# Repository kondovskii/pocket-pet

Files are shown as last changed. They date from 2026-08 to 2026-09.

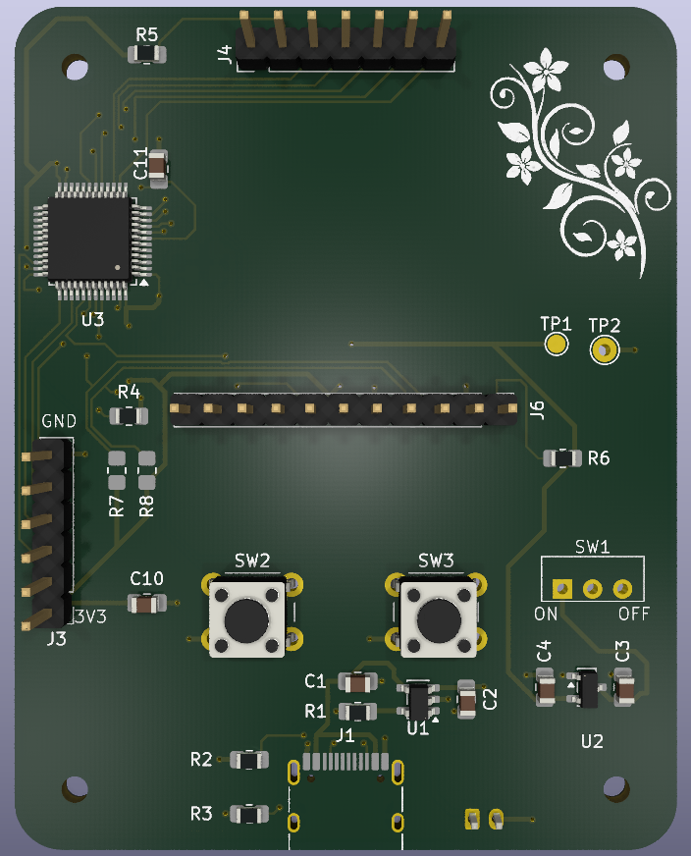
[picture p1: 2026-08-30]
docs/render-top.png

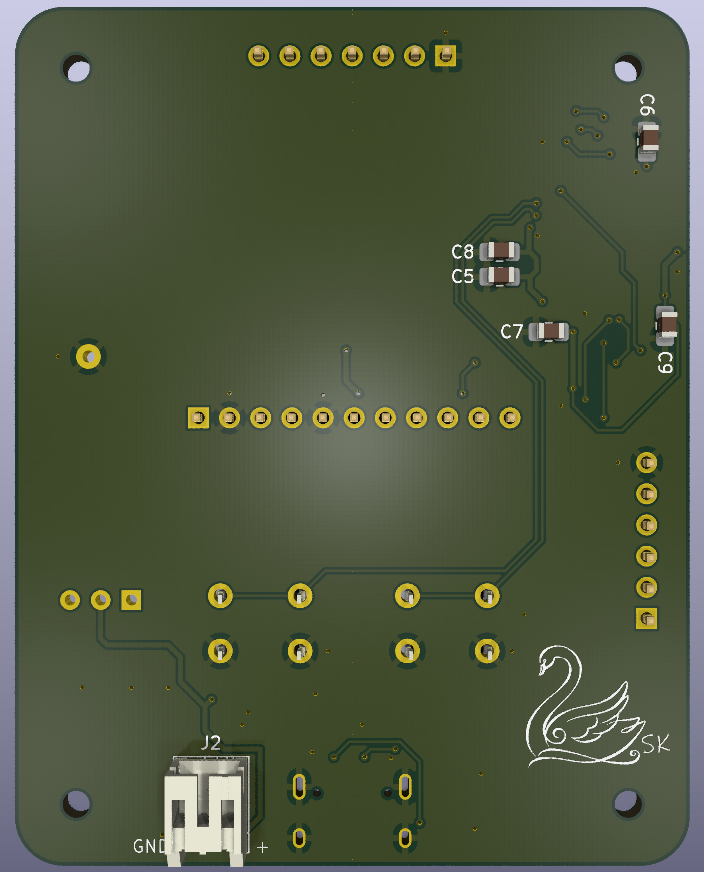
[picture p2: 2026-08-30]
docs/render-bottom.png

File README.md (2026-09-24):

# Pocket Pet

Battery-powered handheld virtual pet on a custom 2-layer PCB. STM32L433,
FreeRTOS, hand-written SSD1306 driver, wake-on-motion.

**Status:** working. Board assembled and running the full firmware — display,
accelerometer, buttons, and battery power all verified on the custom hardware.

## Why this project

Built to close four specific gaps: custom PCB design, bare-metal ARM
programming, RTOS usage, and datasheet-level driver work. Every part was chosen
and every driver written from the datasheet rather than pulled from a library,
so that each decision is defensible.

## Hardware

| Block | Part | Notes |
|---|---|---|
| MCU | STM32L433CCT6 (LQFP-48) | Cortex-M4F, 256K flash, low-power STOP2 modes |
| Charger | MCP73831 | ~196 mA charge current (R_PROG = 5.1 k) |
| Regulator | MCP1700-3302 | 3.3 V LDO, low quiescent current |
| Input | USB-C, charge only | 5.1 k CC1/CC2 pull-downs for correct sink advertisement |
| Display | SSD1306 128x64, SPI | Hand-written driver, no vendor library |
| Motion | LIS3DH, I2C | Hand-written driver; soldered direct, isolatable via R6 |
| Battery | 500 mAh LiPo | JST-PH |

2-layer FR4, designed in KiCad, fabricated by JLCPCB.

## Design decisions

**MSI at 32 MHz, not HSI16, not 80 MHz.** MSI is the oscillator the L4 wakes on
coming out of STOP mode, and it can be trimmed against an LSE crystal. 32 MHz
was chosen over the 80 MHz maximum because the workload — a 128x64 display
refresh and an accelerometer read — does not need it, and lower active current
is free. The power story for a battery device is duty cycle (STOP2 at roughly
1 uA versus milliamps awake), not clock rate.

**USB-C is charge-only.** No USB data. The 5.1 k pull-downs on CC1 and CC2 are
what make a charger treat the board as a valid sink; without them a compliant
USB-C supply provides no VBUS at all. Programming and debug go over SWD, which
keeps the firmware simpler and the BOM smaller.

**0 ohm jumpers on the peripheral rails.** R5 and R6 sit in series with the
display and accelerometer supplies so either can be cut to measure that
peripheral's current draw in isolation, or to remove it from the picture while
debugging.

**I2C pull-ups fitted but not populated.** R7 and R8 are marked DNP because the
LIS3DH module carries its own. Measured at 10 k, which is weak for 400 kHz on
a board with no ground plane, so the bus runs at 100 kHz — the workload is
roughly 60 bytes per second, so there is nothing to gain from the higher rate
and the slower edges have four times the rise-time margin.

**Peripherals soldered directly.** The original plan was female headers so
modules could be swapped. They were dropped because SW1, the power switch, is
surface-mounted flat to the board and cannot rise with them — sockets would
have left it recessed roughly 8.5 mm below the display plane and complicated
the enclosure. The 0 ohm rail jumpers (R5, R6) preserve the debugging benefit:
either peripheral can be isolated or current-measured by lifting one resistor.

**SWD broken out to a 6-pin header** with SWDIO, SWCLK, SWO, NRST, 3V3 and GND,
in ST-Link pin order.

## Display driver

Written from the SSD1306 datasheet rather than pulled from a library: SPI
transport with manual DC and CS control, the full initialisation sequence, a
1024-byte framebuffer, Bresenham line drawing, and a 5x7 column-major font.

**Draw to RAM, flush once.** Every primitive writes to the framebuffer and
nothing reaches the panel until `ssd1306_update_screen()`. Frames appear whole
rather than building up visibly, and the flush is a single 1024-byte SPI burst
instead of hundreds of small transfers.

**The font is column-major** because that matches the controller's own vertical
byte layout, so rendering a glyph is a single bit test per pixel with no
transposition.

**Clipping lives in one place.** Only `ssd1306_draw_pixel()` bounds-checks;
lines, rectangles and text all inherit it. One guard to get right instead of
six, and no way for them to disagree.

**Validated on a NUCLEO-L432KC with a 7-pin SPI module before the custom boards
arrived**, so that display bring-up and board bring-up could be debugged
independently. A blank screen on the custom board now means a hardware fault,
not an unproven driver.

## Motion driver

I2C driver for the LIS3DH, written from the datasheet: register map, burst
reads, and a WHO_AM_I identity check that fails loudly rather than returning
plausible garbage.

**Auto-increment must be requested explicitly.** Bit 7 of the register address
tells the part to advance its internal pointer across a burst. Without it,
reading six bytes from `OUT_X_L` returns the same register six times — all
three axes identical, which looks exactly like a dead sensor rather than a
protocol mistake.

**Block Data Update is enabled** so the part cannot refresh an output register
pair between the read of the low byte and the high byte. Without it, occasional
samples are the low half of one reading stitched to the high half of the next.

**Signed arithmetic shift for the 12-bit values.** Output is left-justified
16-bit; high-resolution mode makes only the top 12 bits meaningful. Shifting a
signed type sign-extends and preserves negative readings, where the same shift
on an unsigned type would turn -1 into 4095.

**The I2C address depends on the board, not the chip.** On the Nucleo bench
wiring SA0 and CS float, and the module's own strapping gives 0x19. On the
custom board J6 ties SA0 to ground and CS to 3V3, giving 0x18. The address
therefore lives in `pocket_pet_pins.h` behind a board selector rather than in
the driver, because it is a board fact.

## RTOS architecture

Three tasks, no shared state.

    inputTask    polls and debounces the buttons, detects shake, publishes events
    petTask      owns the pet state, applies events, ticks it forward once a second
    displayTask  redraws at 8 fps, taking a new state when one is available

Tasks communicate only through queues, and the pet state is passed **by value**
rather than by pointer — each task works on its own copy, so there is no shared
memory, no mutex, and no race to get wrong.

The two queues have deliberately different depths. The state queue is depth 1
because the display only ever cares about the newest state; a deeper one would
just mean rendering stale frames. The event queue is depth 4 because a dropped
button press is a bug, where a dropped frame is not.

**Input is edge-triggered, not level.** A press registers on the
released-to-pressed transition, so holding a button feeds the pet once rather
than continuously.

**The display task runs on a timer, not on the queue.** It was originally
blocked on `osWaitForever`, which meant it only redrew when the pet state
changed — once a second, far too slow for animation. It now wakes every 125 ms
and takes a new state if one is waiting, so rendering rate and simulation rate
are decoupled.

## Game design

Three stats decay on separate timescales: hunger fastest, then mood, then
energy. Any stat reaching zero starts a two-minute distress countdown with a
visible warning; ignoring it kills the pet. The countdown exists so that death
is a consequence of ignoring something, not a surprise.

**The lowest stat decides the pet's expression**, so it looks as bad as its
worst problem rather than averaging out and hiding the thing the player needs
to notice.

**Two buttons, four actions.** Left feeds. Right plays on a short press and
toggles sleep on a one-second hold. Shaking the board is a third input,
detected by comparing squared acceleration magnitude against a threshold —
squared, so the comparison needs no square root and no floating point.

**Sleep is the only way to recover energy**, and playing costs it, so the
stats interact rather than being three independent bars.

**Actions trigger a two-second reaction animation.** This confirms the press
registered, and gives the less-frequently-seen animations a reason to exist —
most moods map to slow-moving stats you rarely watch change.

## Known issues (v1.0)

Found during a design review after the boards were already at fab. Documented
rather than hidden — these are the v1.1 fix list.

- **No ground pour on either layer.** Every return path is a narrow trace, which
  raises loop inductance and leaves the MCP73831 with no thermal copper. Expect
  the charger to run warm and possibly fold back current.
- **No reverse-polarity protection on the battery input.** A backwards cell would
  destroy the charger. Mitigated only by silkscreen.
- **No load-sharing.** The load hangs off the battery node, so the board is not
  designed to run from USB with no cell installed.
- **No battery voltage sensing.** No way to report state of charge. A divider to
  an ADC pin is the fix.
- **Decoupling placement is loose** — several caps sit millimetres from the pins
  they serve, which without a plane makes them largely ineffective.
- **STAT pin unconnected**, so there is no charge indicator LED.
- Silkscreen needs a cleanup pass: unannotated mounting holes, overlapping value
  text, no pin-1 markers or header labels.
- **Cold joints on the USB-C VBUS pin killed the first assembly attempt.**
  VBUS and GND have multiple redundant pins; CC1 and CC2 have exactly one
  each, so a single bad joint silently kills power negotiation with no other
  symptom. Worth probing CC-to-GND for 5.1 k before troubleshooting anything
  else.
- **The Nucleo-32's ST-Link cannot program an external target.** Unlike
  Nucleo-64 and -144, it has no break-out SWD connector — the debugger is
  hardwired to the on-board MCU, and CN2 is reserved for reflashing the
  ST-Link's own processor. A standalone ST-Link V2 is required. Worth knowing
  before planning a bring-up around a Nucleo.
- Debug sessions corrupt I²C. With SWD active, lis3dh_init() fails intermittently; disconnecting the debugger makes it reliable.  SWDIO and SWCLK run adjacent to the I²C lines with no ground plane between them. Worth knowing that on this board a peripheral failure seen under the debugger may not be a real failure.
- **Task stacks were too small, and the first fix silently undid itself.**
  The display task ran on CubeMX's default 512 bytes, which `snprintf`, newlib
  reentrancy and the scaled bitmap blit comfortably exceed. The symptom was a
  HardFault minutes after boot, triggered by bursts of input, with nothing
  obviously stack-related in the trace. It was fixed once by hand, but the
  default task's stack size lives in generated code outside the USER CODE
  markers, so the next CubeMX regeneration quietly reverted it. Now set in the
  .ioc at 2 KB per task, with configCHECK_FOR_STACK_OVERFLOW enabled so any
  future overflow halts in a named hook rather than surfacing as an unrelated
  fault.
- **The battery arrived with its JST housing wired backwards.** With no
  reverse-polarity protection on v1.0 that would have destroyed the charger.
  Worth measuring cell polarity against the board's silkscreen before every
  first connection.
- **Cheap USB-C charger modules often omit the CC pull-downs.** A TP4056
  module appeared dead on a compliant USB-C supply because it never
  negotiated; it worked immediately from a legacy USB-A source. The same
  5.1 k resistors this board fits as R2/R3.
  - **Changing I2C speed in CubeMX did not update the generated timing register.**
  The .ioc read Standard Mode while `MX_I2C1_Init()` still carried the Fast
  Mode timing value, so the bus ran at 400 kHz regardless. With 10 k pull-ups
  and no ground plane that was marginal, and produced intermittent LIS3DH
  failures that looked like a driver or wiring fault. Toggling the mode and
  disabling custom timing both failed to force a recalculation; the value had
  to be entered by hand. Verify `hi2c1.Init.Timing` in i2c.c after any speed
  change rather than trusting the .ioc.

## Repository layout

    hardware/pocket-pet/     KiCad project, fab outputs under fab/
    firmware/pocket-pet-nucleo/   Bring-up project, NUCLEO-L432KC
    firmware/pocket-pet-board/    Custom board project
    docs/                    Schematic PDF, renders, BOM

## Building the firmware

Requires STM32CubeIDE. Import the project with "Copy projects into workspace"
unchecked so the IDE edits the repo in place; keep the workspace outside the
repository. The .ioc file is the source of truth for pin configuration — if you
change pins, regenerate from CubeMX rather than editing generated code.
Any value in generated code outside the USER CODE markers — task stack sizes,
heap size, peripheral settings — must be changed in the .ioc, not the source.
Hand edits there are overwritten on the next regeneration without warning.

## Sprites

Sprite data is not included in this repository. The bunny animations are from
[VegaJourney's 32x32 Bunny pack](https://toffeecraft.itch.io/bunny-pixel-animations) (licence permits use but
not redistribution), converted to 1-bit bitmaps.

To build: copy `firmware/common/pet_sprites.h.template` to `pet_sprites.h`
and supply your own sprite arrays. Any 1-bit bitmap works — 
`ssd1306_draw_bitmap()` takes row-major, MSB-first data, which is what
[image2cpp](https://javl.github.io/image2cpp/) produces with horizontal
orientation selected.

## License

MIT

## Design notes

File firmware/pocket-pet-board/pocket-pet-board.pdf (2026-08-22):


22/08/2026

pocket-pet-board Project
Configuration Report

## 1. Description

### 1.1. Project

Project Name | pocket-pet-board
Board Name | custom
Generated with: | STM32CubeMX 6.18.1
Date | 08/22/2026

### 1.2. MCU

MCU Series | STM32L4
MCU Line | STM32L4x3
MCU name | STM32L433CCTx
MCU Package | LQFP48
MCU Pin number | 48

### 1.3. Core(s) information

Core(s) | Arm Cortex-M4

## 2. Pinout Configuration

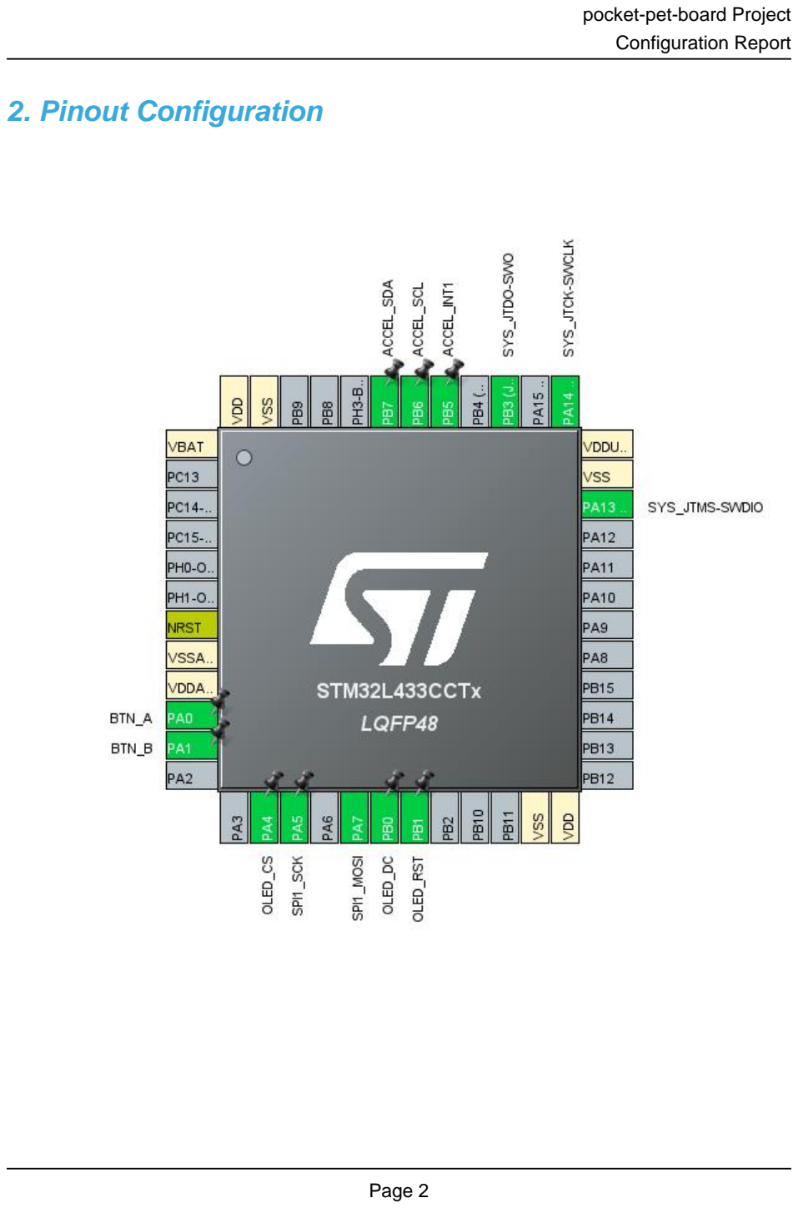
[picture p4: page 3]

## 3. Pins Configuration

Pin Number LQFP48 | Pin Name (function after reset) | Pin Type | Alternate Function(s) | Label
1 | VBAT | Power
7 | NRST | Reset
8 | VSSA/VREF- | Power
9 | VDDA/VREF+ | Power
10 | PA0 * | I/O | GPIO_Input | BTN_A
11 | PA1 * | I/O | GPIO_Input | BTN_B
14 | PA4 * | I/O | GPIO_Output | OLED_CS
15 | PA5 | I/O | SPI1_SCK
17 | PA7 | I/O | SPI1_MOSI
18 | PB0 * | I/O | GPIO_Output | OLED_DC
19 | PB1 * | I/O | GPIO_Output | OLED_RST
23 | VSS | Power
24 | VDD | Power
34 | PA13 (JTMS-SWDIO) | I/O | SYS_JTMS-SWDIO
35 | VSS | Power
36 | VDDUSB | Power
37 | PA14 (JTCK-SWCLK) | I/O | SYS_JTCK-SWCLK
39 | PB3 (JTDO-TRACESWO) | I/O | SYS_JTDO-SWO
41 | PB5 * | I/O | GPIO_Input | ACCEL_INT1
42 | PB6 | I/O | I2C1_SCL | ACCEL_SCL
43 | PB7 | I/O | I2C1_SDA | ACCEL_SDA
47 | VSS | Power
48 | VDD | Power

* The pin is affected with an I/O function

## 4. Clock Tree Configuration

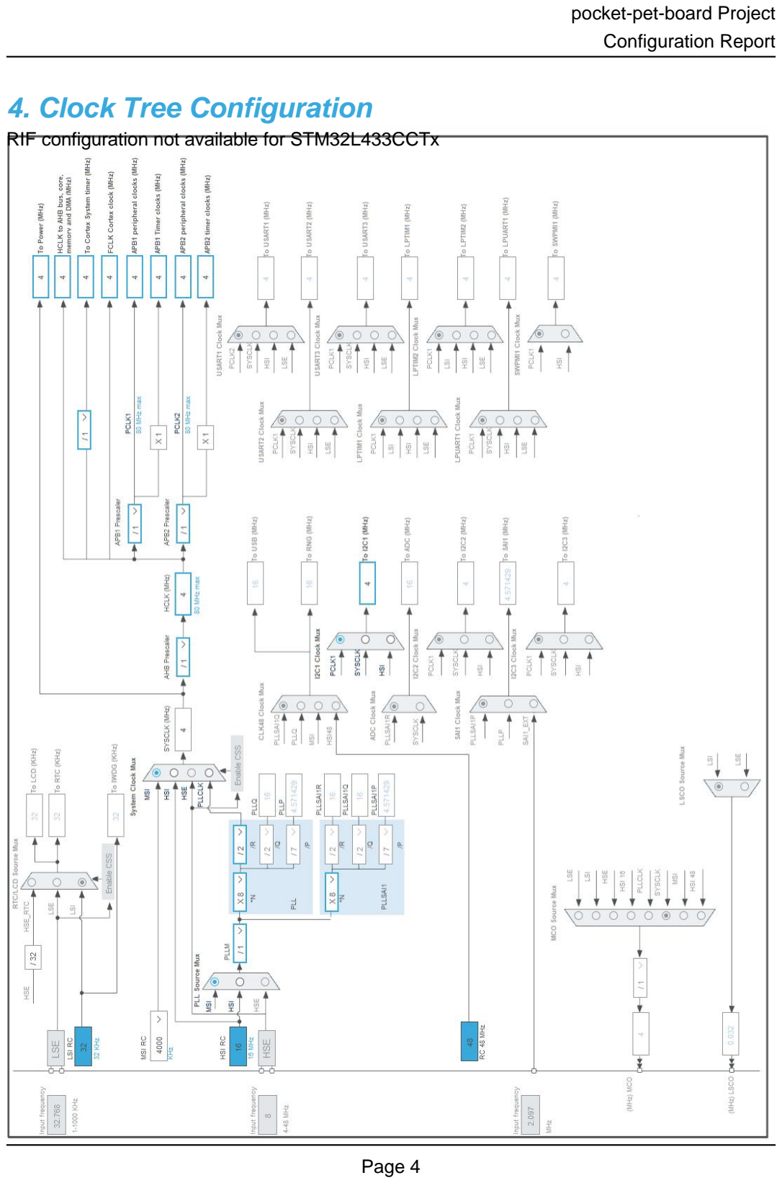
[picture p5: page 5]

RIF configuration not available for STM32L433CCTx

## 1. Power Consumption Calculator report

### 1.1. Microcontroller Selection

Series | STM32L4
Line | STM32L4x3
MCU | STM32L433CCTx
Datasheet | DS11449_Rev3

### 1.2. Parameter Selection

Temperature | 25
Vdd | 3.0

### 1.3. Battery Selection

Battery | Li-SOCL2(A3400)
Capacity | 3400.0 mAh
Self Discharge | 0.08 %/month
Nominal Voltage | 3.6 V
Max Cont Current | 100.0 mA
Max Pulse Current | 200.0 mA
Cells in series | 1
Cells in parallel | 1

### 1.4. Sequence

Step | Step1 | Step2
Mode | RUN | STOP2
Vdd | 3.0 | 3.0
Voltage Source | Battery | Battery
Range | Range1-High | NoRange
Fetch Type | SRAM2 | n/a
CPU Frequency | 80 MHz | 0 Hz
Clock Configuration | HSE BYP PLL | ALL CLOCKS OFF
Clock Source Frequency | 4 MHz | 0 Hz
Peripherals
Additional Cons. | 0 mA | 0 mA
Average Current | 8.71 mA | 1.06 µA
Duration | 0.1 ms | 0.9 ms
DMIPS | 100.0 | 0.0
Ta Max | 103.51 | 105
Category | In DS Table | In DS Table

### 1.5. Results

Sequence Time | 1 ms | Average Current | 871.95 µA
Battery Life | 5 months, 9 days, 16 hours | Average DMIPS | 100.0 DMIPS

### 1.6. Chart

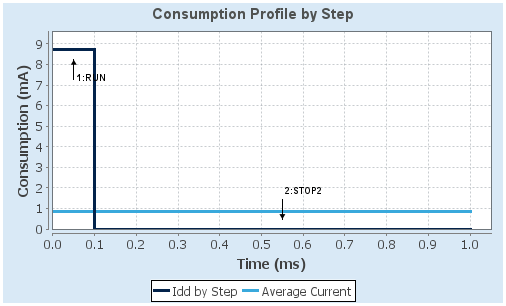
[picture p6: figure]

## 2. Software Project

### 2.1. Project Settings

Name | Value
Project Name | pocket-pet-board
Project Folder | C:\projects\pocket-pet\firmware\pocket-pet-board
Toolchain / IDE | EWARM V8.32
Firmware Package Name and Version | STM32Cube FW_L4 V1.18.2
Application Structure | Advanced
Generate Under Root | No
Do not generate the main() | No
Minimum Heap Size | 0x200
Minimum Stack Size | 0x400

### 2.2. Code Generation Settings

Name | Value
STM32Cube MCU packages and embedded software | Copy all used libraries into the project folder
Generate peripheral initialization as a pair of '.c/.h' files | No
Backup previously generated files when re-generating | No
Keep User Code when re-generating | Yes
Delete previously generated files when not re-generated | Yes
Set all free pins as analog (to optimize the power consumption) | No
Enable Full Assert | No

### 2.3. Advanced Settings - Generated Function Calls

Rank | Function Name | Peripheral Instance Name
1 | SystemClock_Config | RCC
2 | MX_GPIO_Init | GPIO
3 | MX_I2C1_Init | I2C1
4 | MX_SPI1_Init | SPI1

## 3. Peripherals and Middlewares Configuration

### 3.1. I2C1

I2C: I2C
3.1.1. Parameter Settings:

Timing configuration:

Custom Timing | Disabled
I2C Speed Mode | Standard Mode
I2C Speed Frequency (KHz) | 100
Rise Time (ns) | 100
Fall Time (ns) | 100
Coefficient of Digital Filter | 0
Analog Filter | Enabled
Timing | 0x00100D14 *
Slave Features:
Clock No Stretch Mode | Disabled
General Call Address Detection | Disabled
Primary Address Length selection | 7-bit
Dual Address Acknowledged | Disabled
Primary slave address | 0

### 3.2. RCC

3.2.1. Parameter Settings:

System Parameters:

VDD voltage (V) | 3.3
Instruction Cache | Enabled
Prefetch Buffer | Disabled
Data Cache | Enabled
Flash Latency(WS) | 0 WS (1 CPU cycle)
RCC Parameters:
HSI Calibration Value | 16
MSI Calibration Value | 0
MSI Auto Calibration | Disabled
HSE Startup Timout Value (ms) | 100
LSE Startup Timout Value (ms) | 5000
Power Parameters:
Power Regulator Voltage Scale | Power Regulator Voltage Scale 1

### 3.3. SPI1

Mode: Transmit Only Master
3.3.1. Parameter Settings:

Basic Parameters:

Frame Format | Motorola
Data Size | 8 Bits *
First Bit | MSB First
Clock Parameters:
Prescaler (for Baud Rate) | 2
Baud Rate | 2.0 MBits/s *
Clock Polarity (CPOL) | Low
Clock Phase (CPHA) | 1 Edge
Advanced Parameters:
CRC Calculation | Disabled
NSSP Mode | Enabled
NSS Signal Type | Software

### 3.4. SYS

Debug: Trace Asynchronous Sw Timebase Source: SysTick

* User modified value

## 4. System Configuration

### 4.1. GPIO configuration

IP | Pin | Signal | GPIO mode | GPIO pull/up pull down | Max Speed | User Label
I2C1 | PB6 | I2C1_SCL | Alternate Function Open Drain | No pull-up and no pull-down | Very High * | ACCEL_SCL
| PB7 | I2C1_SDA | Alternate Function Open Drain | No pull-up and no pull-down | Very High * | ACCEL_SDA
SPI1 | PA5 | SPI1_SCK | Alternate Function Push Pull | No pull-up and no pull-down | Very High *
| PA7 | SPI1_MOSI | Alternate Function Push Pull | No pull-up and no pull-down | Very High *
SYS | PA13 (JTMS-SWDIO) | SYS_JTMS-SWDIO | n/a | n/a | n/a
| PA14 (JTCK-SWCLK) | SYS_JTCK-SWCLK | n/a | n/a | n/a
| PB3 (JTDO-TRACESWO ) | SYS_JTDO-SWO | n/a | n/a | n/a
GPIO | PA0 | GPIO_Input | Input mode | Pull-up * | n/a | BTN_A
| PA1 | GPIO_Input | Input mode | Pull-up * | n/a | BTN_B
| PA4 | GPIO_Output | Output Push Pull | No pull-up and no pull-down | Low | OLED_CS
| PB0 | GPIO_Output | Output Push Pull | No pull-up and no pull-down | Low | OLED_DC
| PB1 | GPIO_Output | Output Push Pull | No pull-up and no pull-down | Low | OLED_RST
| PB5 | GPIO_Input | Input mode | No pull-up and no pull-down | n/a | ACCEL_INT1

### 4.2. DMA configuration

nothing configured in DMA service

### 4.3. NVIC configuration

4.3.1. NVIC
Interrupt Table | Enable | Preenmption Priority | SubPriority
Non maskable interrupt | true | 0 | 0
Hard fault interrupt | true | 0 | 0
Memory management fault | true | 0 | 0
Prefetch fault, memory access fault | true | 0 | 0
Undefined instruction or illegal state | true | 0 | 0
System service call via SWI instruction | true | 0 | 0
Debug monitor | true | 0 | 0
Pendable request for system service | true | 0 | 0
System tick timer | true | 15 | 0
PVD/PVM1/PVM2/PVM3/PVM4 interrupts through EXTI lines 16/35/36/37/38 | unused
Flash global interrupt | unused
RCC global interrupt | unused
I2C1 event interrupt | unused
I2C1 error interrupt | unused
SPI1 global interrupt | unused
FPU global interrupt | unused
4.3.2. NVIC Code generation
Enabled interrupt Table | Select for init sequence ordering | Generate IRQ handler | Call HAL handler
Non maskable interrupt | false | true | false
Hard fault interrupt | false | true | false
Memory management fault | false | true | false
Prefetch fault, memory access fault | false | true | false
Undefined instruction or illegal state | false | true | false
System service call via SWI instruction | false | true | false
Debug monitor | false | true | false
Pendable request for system service | false | true | false
System tick timer | false | true | true

* User modified value

## 5. System Views

5.1. Category view
5.1.1. Current

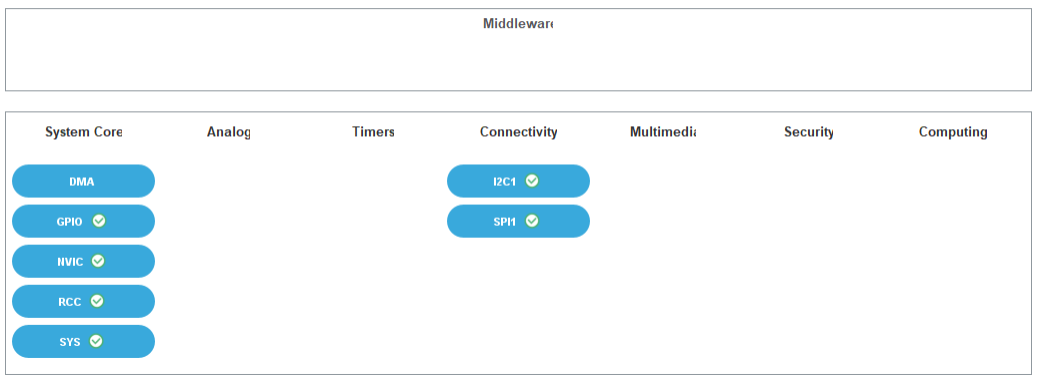
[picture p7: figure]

## 6. Docs & Resources

Type | Link
BSDL files | https://www.st.com/resource/en/bsdl_model/stm32l4_bsdl.zip
IBIS models | https://www.st.com/resource/en/ibis_model/stm32l4_ibis.zip
System View Description | https://www.st.com/resource/en/svd/stm32l4_svd.zip
Presentations | https://www.st.com/resource/en/product_presentation/stm32-stm8_embedded_software_solutions.pdf
Presentations | https://www.st.com/resource/en/product_presentation/stm32_eval-tools_portfolio.pdf
Presentations | https://www.st.com/resource/en/product_presentation/stm32_stm8_functi onal-safety-packages.pdf
Presentations | https://www.st.com/resource/en/product_presentation/stm32-stm8_software_development_tools.pdf
Presentations | https://www.st.com/resource/en/product_presentation/microcontrollers-stm32-family-overview.pdf
Presentations | https://www.st.com/resource/en/product_presentation/microcontrollers-stm32l4-series-product-overview.pdf
Brochures | https://www.st.com/resource/en/brochure/brstm32ulp.pdf
Flyers | https://www.st.com/resource/en/flyer/flstm32l4.pdf
Flyers | https://www.st.com/resource/en/flyer/flstm32nucleo.pdf
Flyers | https://www.st.com/resource/en/flyer/flstm32trust.pdf
Product Certifications | https://www.st.com/resource/en/certification_document/sesip-2000002-01-cert.pdf
Product Certifications | https://www.st.com/resource/en/certification_document/sesip-2000002-01-st2.pdf
Product Certifications | https://www.st.com/resource/en/certification_document/psa-certificate_stm32l4.pdf
Security Bulletin | https://www.st.com/resource/en/technical_note/tn1489-security-bulletin-tn1489stpsirt-physical-attacks-on-stm32-and-stm32cube-firmware-stmicroelectronics.pdf

Application Notes | https://www.st.com/resource/en/application_note/an1709-emc-design-guide-for-stm8-stm32-and-legacy-mcus-stmicroelectronics.pdf
Application Notes | https://www.st.com/resource/en/application_note/an4221-i2c-protocol-used-in-the-stm32-bootloader-stmicroelectronics.pdf
Application Notes | https://www.st.com/resource/en/application_note/an4555-getting-started-with-stm32l4-series-and-stm32l4-series-hardware-development-stmicroelectronics.pdf
Application Notes | https://www.st.com/resource/en/application_note/an4612-migrating-from-stm32l1-series-to-stm32l4-series-and-stm32l4-series-microcontrollers-stmicroelectronics.pdf
Application Notes | https://www.st.com/resource/en/application_note/an4616-migrating-from-stm32f401-and-stm32f411-lines-to-stm32l4-series-and-stm32l4-series-microcontrollers-stmicroelec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
Application Notes | https://www.st.com/resource/en/application_note/an4621-stm32l4-and-stm32l4-ultralowpower-features-overview-stmicroelectronics.pdf
Application Notes | https://www.st.com/resource/en/application_note/an4629-adc-hardware-oversampling-for-microcontrollers-of-the-stm32-l0-and-l4-series-stmicroelectronics.pdf
Application Notes | https://www.st.com/resource/en/application_note/an4649-migrating-from-stm32f1-series-to-stm32l4-series--stm32l4-series-microntrollers-stmicroelectronics.pdf
Application Notes | https://www.st.com/resource/en/application_note/an4655-virtually-increasing-the-number-of-serial-communication-peripherals-in-stm32-applications-stmicroelectronics.p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
Application Notes | https://www.st.com/resource/en/application_note/an4726-stm32cube-firmware-examples-for-stm32l4-series-and-stm32l4-series-stmicroelectronics.pdf
Application Notes | https://www.st.com/resource/en/application_note/an4729-stm32l0l4-firewall-overview-stmicroelectronics.pdf
Application Notes | https://www.st.com/resource/en/application_note/an4730-using-the-firewall-embedded-in-stm32l0l4l4-series-mcus-for-secure-access-to-sensitive-parts-of-code-and-data-s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
Application Notes | https://www.st.com/resource/en/application_note/an4750-handling-of-soft-errors-in-stm32-applications-stmicroelectronics.pdf

Application Notes | https://www.st.com/resource/en/application_note/an4754-migrating-between-stm32l486xx476xx-and-stm32l443xx433xx-microcontrollers-stmicroelectronics.pdf
Application Notes | https://www.st.com/resource/en/application_note/an4803-highspeed-si-simulations-using-ibis-and-boardlevel-simulations-using-hyperlynx-si-on-stm32-mcus-and-mpus-stmic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
Application Notes | https://www.st.com/resource/en/application_note/an4809-migrating-between-stm32l0-series-and-stm32l4-series--stm32l4-series-microcontrollers-stmicroelectronics.pdf
Application Notes | https://www.st.com/resource/en/application_note/an4821-migrating-from-stm32f405415-line-and-stm32f407417-line-to-stm32l4-series-and-stm32l4-series-microcontrollers-s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
Application Notes | https://www.st.com/resource/en/application_note/an4831-migrating-from-stm32f2x5-line-to-stm32l4-series-and-stm32l4-series-microcontrollers-stmicroelectronics.pdf
Application Notes | https://www.st.com/resource/en/application_note/an4832-migrating-from-stm32f303-line-to-stm32l4-series-and-stm32l4-series-microcontrollers-stmicroelectronics.pdf
Application Notes | https://www.st.com/resource/en/application_note/an4990-getting-started-with-sigmadelta-digital-interface-on-applicable-stm32-microcontrollers-stmicroelectronics.pdf
Application Notes | https://www.st.com/resource/en/application_note/an4995-using-an-electromyogram-technique-to-detect-muscle-activity-stmicroelectronics.pdf
Application Notes | https://www.st.com/resource/en/application_note/an5012-analogtodigital-audio-conversion-example-using-stm32l4-series-microcontroller-peripherals-stmicroelectronics.p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
Application Notes | https://www.st.com/resource/en/application_note/an5027-interfacing-pdm-digital-microphones-using-stm32-mcus-and-mpus-stmicroelectronics.pdf
Application Notes | https://www.st.com/resource/en/application_note/an4899-stm32-microcontroller-gpio-hardware-settings-and-lowpower-consumption-stmicroelectronics.pdf
Application Notes | https://www.st.com/resource/en/application_note/an5612-esd-protection-of-stm32-mcus-and-mpus-stmicroelectronics.pdf

Application Notes | https://www.st.com/resource/en/application_note/an4991-how-to-wake-up-an-stm32-microcontroller-from-lowpower-mode-with-the-usart-or-the-lpuart-stmicroelectronics.pdf
Application Notes | https://www.st.com/resource/en/application_note/an4838-introduction-to-memory-protection-unit-management-on-stm32-mcus-stmicroelectronics.pdf
Application Notes | https://www.st.com/resource/en/application_note/an4879-introduction-to-usb-hardware-and-pcb-guidelines-using-stm32-mcus-stmicroelectronics.pdf
Application Notes | https://www.st.com/resource/en/application_note/an5372-migrating-from-stm32l4-and-stm32l4--to-stm32u5-mcus-stmicroelectronics.pdf
Application Notes | https://www.st.com/resource/en/application_note/an5225-introduction-to-usb-typec-power-delivery-for-stm32-mcus-and-mpus-stmicroelectronics.pdf
Application Notes | https://www.st.com/resource/en/application_note/an4777-how-to-optimize-power-consumption-on-stm32-mcus-stmicroelectronics.pdf
Application Notes | https://www.st.com/resource/en/application_note/an4894-how-to-use-eeprom-emulation-on-stm32-mcus-stmicroelectronics.pdf
Application Notes | https://www.st.com/resource/en/application_note/an5537-how-to-use-adc-oversampling-techniques-to-improve-signaltonoise-ratio-on-stm32-mcus-stmicroelectronics.pdf
Application Notes | https://www.st.com/resource/en/application_note/an5690-how-to-use-vrefbuf-peripheral-on-stm32-mcus-and-mpus-stmicroelectronics.pdf
Application Notes | https://www.st.com/resource/en/application_note/an4230-introduction-to-random-number-generation-validation-using-the-nist-statistical-test-suite-for-stm32-mcus-and-m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
Application Notes | https://www.st.com/resource/en/application_note/an2548-introduction-to-dma-controller-for-stm32-mcus-stmicroelectronics.pdf
Application Notes | https://www.st.com/resource/en/application_note/an2867-guidelines-for-oscillator-design-on-stm8afals-and-stm32-mcusmpus-stmicroelectronics.pdf
Application Notes | https://www.st.com/resource/en/application_note/an3236-how-to-increase-the-number-of-touchkeys-for-touch-sensing-applications-on-stm32-mcus-stmicroelectronics.pdf

Application Notes | https://www.st.com/resource/en/application_note/an3960-guidelines-for-esd-for-touch-sensing-applications-on-stm32-mcus-stmicroelectronics.pdf
Application Notes | https://www.st.com/resource/en/application_note/an4013-introduction-to-timers-for-stm32-mcus-stmicroelectronics.pdf
Application Notes | https://www.st.com/resource/en/application_note/an4277-how-to-use-pwm-shutdown-for-motor-control-and-digital-power-conversion-on-stm32-mcus-stmicroelectronics.pdf
Application Notes | https://www.st.com/resource/en/application_note/an4299-how-to-improve-conducted-noise-robustness-for-touch-sensing-applications-on-stm32-mcus-stmicroelectronics.pdf
Application Notes | https://www.st.com/resource/en/application_note/an4310-how-to-choose-the-sampling-capacitor-for-touch-sensing-applications-on-stm32-mcus-stmicroelectronics.pdf
Application Notes | https://www.st.com/resource/en/application_note/an4312-how-to-design-surface-sensors-for-touch-sensing-applications-on-stm32-mcus-stmicroelectronics.pdf
Application Notes | https://www.st.com/resource/en/application_note/an4316-how-to-tune-touch-sensing-applications-on-stm32-mcus-stmicroelectronics.pdf
Application Notes | https://www.st.com/resource/en/application_note/an4635-how-to-optimize-lpuart-power-consumption-on-stm32-mcus-stmicroelectronics.pdf
Application Notes | https://www.st.com/resource/en/application_note/an4908-getting-started-with-usart-automatic-baud-rater-detection-for-stm32-mcus-stmicroelectronics.pdf
Application Notes | https://www.st.com/resource/en/application_note/an5156-introduction-to-security-for-stm32-mcus-stmicroelectronics.pdf
Application Notes | https://www.st.com/resource/en/application_note/an5543-guidelines-for-enhanced-spi-communication-on-stm32-mcus-and-mpus-stmicroelectronics.pdf
Application Notes | https://www.st.com/resource/en/application_note/cd00211314-how-to-optimize-the-adc-accuracy-in-the-stm32-mcus-stmicroelectronics.pdf
Application Notes | https://www.st.com/resource/en/application_note/an2639-soldering-recommendations-and-package-information-for-leadfree-ecopack2-mcus-and-mpus-stmicroelectronics.pdf

Application Notes | https://www.st.com/resource/en/application_note/an3154-how-to-use-can-protocol-in-bootloader-on-stm32-mcus-stmicroelectronics.pdf
Application Notes | https://www.st.com/resource/en/application_note/an6099-migrating-from-stm32l4-to-stm32u0-mcus-stmicroelectronics.pdf
Application Notes | https://www.st.com/resource/en/application_note/an4566-how-to-extend-the-dac-performance-on-stm32-mcus-stmicroelectronics.pdf
Application Notes | https://www.st.com/resource/en/application_note/an5105-getting-started-with-touch-sensing-control-on-stm32-mcus-stmicroelectronics.pdf
Application Notes | https://www.st.com/resource/en/application_note/an6051-migrating-from-stm32l4-and-stm32l4-to-stm32u3-mcus-stmicroelectronics.pdf
Application Notes | https://www.st.com/resource/en/application_note/an5647-the-goertzel-algorithm-to-compute-individual-terms-of-the-discrete-fourier-transform-dft-in-stm32-products-stm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
Application Notes | https://www.st.com/resource/en/application_note/an2606-introduction-to-system-memory-boot-mode-on-stm32-mcus-stmicroelectronics.pdf
Application Notes | https://www.st.com/resource/en/application_note/an5036-guidelines-for-thermal-management-on-stm32-mcus-and-mpus-stmicroelectronics.pdf
Application Notes | https://www.st.com/resource/en/application_note/an3126-how-to-use-dac-for-audio-and-waveform-generation-on-stm32-mcus-and-mpus-stmicroelectronics.pdf
Application Notes | https://www.st.com/resource/en/application_note/an3155-how-to-use-usart-protocol-in-bootloader-on-stm32-mcus-stmicroelectronics.pdf
Application Notes | https://www.st.com/resource/en/application_note/an3156-how-to-use-usb-dfu-protocol-in-bootloader-on-stm32-mcus-stmicroelectronics.pdf
Application Notes | https://www.st.com/resource/en/application_note/an4286-how-to-use-spi-protocol-in-bootloader-on-stm32-mcus-stmicroelectronics.pdf
Application Notes | https://www.st.com/resource/en/application_note/an4746-how-to-optimize-power-and-performance-on-stm32l4-and-stm32l4-mcus-stmicroelectronics.pdf
Application Notes | https://www.st.com/resource/en/application_note/an4759-introduction-to-using-the-hardware-realtime-clock-rtc-and-the-tamper-management-unit-tamp-for-stm32-mcus-stmic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
Application Notes | https://www.st.com/resource/en/application_note/an4760-introduction-to-

| quadspi-interface-for-stm32-mcus-and-mpus-stmicroelectronics.pdf
Application Notes | https://www.st.com/resource/en/application_note/an4776-how-to-use-generalpurpose-timer-peripheral-on-stm32-mcus-stmicroelectronics.pdf
Application Notes | https://www.st.com/resource/en/application_note/an4989-introduction-to-debug-toolbox-for-stm32-mcus-stmicroelectronics.pdf
Application Notes | https://www.st.com/resource/en/application_note/an5138-migrating-from-stm32l4-and-stm32l4-to-stm32l5-mcus-stmicroelectronics.pdf
Application Notes | https://www.st.com/resource/en/application_note/an5408-migrating-from-stm32l0-stm32l1-and-stm32l4-associated-with-sx12xx-transceivers-to-stm32wl5xex-mcus-stmicroelec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
Errata Sheets | https://www.st.com/resource/en/errata_sheet/es0318-stm32l431xx432xx433xx442xx443xx-device-errata-stmicroelectronics.pdf
Datasheet | https://www.st.com/resource/en/datasheet/dm00257192.pdf
Programming Manuals | https://www.st.com/resource/en/programming_manual/pm0214-stm32-cortexm4-mcus-and-mpus-programming-manual-stmicroelectronics.pdf
Reference Manuals | https://www.st.com/resource/en/reference_manual/rm0394-stm32l41xxx42xxx43xxx44xxx45xxx46xxx-advanced-armbased-32bit-mcus-stmicroelectronics.pdf
Technical Notes & Articles | https://www.st.com/resource/en/technical_note/tn1163-description-of-wlcsp-for-microcontrollers-and-recommendations-for-its-use-stmicroelectronics.pdf
Technical Notes & Articles | https://www.st.com/resource/en/technical_note/tn1205-tape-and-reel-shipping-media-for-stm8-and-stm32-microcontrollers-in-fpn-packages-stmicroelectronics.pdf
Technical Notes & Articles | https://www.st.com/resource/en/technical_note/tn1206-tape-and-reel-shipping-media-for-stm8-and-stm32-microcontrollers-in-qfp-packages-stmicroelectronics.pdf
Technical Notes & Articles | https://www.st.com/resource/en/technical_note/tn1207-tape-and-reel-shipping-media-for-stm8-and-stm32-microcontrollers-in-so-packages-stmicroelectronics.pdf
Technical Notes & Articles | https://www.st.com/resource/en/technical_note/tn1208-tape-and-reel-shipping-media-for-stm8-and-stm32-microcontrollers-in-tssop-and-ssop-packages-stmicroelectronics.p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

Technical Notes & Articles | https://www.st.com/resource/en/technical_note/tn1433-reference-device-marking-schematics-for-stm32-microcontrollers-and-microprocessors-stmicroelectronics.pdf
Technical Notes & Articles | https://www.st.com/resource/en/technical_note/tn1204-tape-and-reel-shipping-media-for-stm32-devices-in-bga-packages-stmicroelectronics.pdf
User Manuals | https://www.st.com/resource/en/user_manual/um2305-stm32l4-and-stm32l4-series-safety-manual-stmicroelectronics.pdf
User Manuals | https://www.st.com/resource/en/user_manual/um3166-stm32l4-and-stm32l4-series-ulcsaiec-607301603351-selftest-library-user-guide-stmicroelectronics.pdf

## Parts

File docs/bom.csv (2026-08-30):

Reference | Qty | Value | LCSC | DNP | Exclude from BOM | Exclude from Board | Exclude from Simulation | Exclude from Position Files | Footprint | Datasheet
C1,C2,C10 | 3 | 4.7uF | C1779 |  |  |  |  | ${EXCLUDE_FROM_POS_FILES} | Capacitor_SMD:C_0805_2012Metric_Pad1.18x1.45mm_HandSolder
C3 | 1 | 1uF | C28323 |  |  |  |  | ${EXCLUDE_FROM_POS_FILES} | Capacitor_SMD:C_0805_2012Metric_Pad1.18x1.45mm_HandSolder
C4 | 1 | 2.2uF | C377773 |  |  |  |  | ${EXCLUDE_FROM_POS_FILES} | Capacitor_SMD:C_0805_2012Metric_Pad1.18x1.45mm_HandSolder
C5,C6,C7,C8,C9,C11 | 6 | 100nF | C49678 |  |  |  |  | ${EXCLUDE_FROM_POS_FILES} | Capacitor_SMD:C_0805_2012Metric_Pad1.18x1.45mm_HandSolder
J1 | 1 | USB_C_Receptacle_USB2.0_16P | C165948 |  |  |  |  | ${EXCLUDE_FROM_POS_FILES} | Connector_USB:USB_C_Receptacle_HRO_TYPE-C-31-M-12 | https://www.usb.org/sites/default/files/documents/usb_type-c.zip
J2 | 1 | Conn_01x02 | C157932 |  |  |  |  | ${EXCLUDE_FROM_POS_FILES} | Connector_JST:JST_PH_S2B-PH-K_1x02_P2.00mm_Horizontal
J3 | 1 | Conn_01x06 |  |  |  |  |  | ${EXCLUDE_FROM_POS_FILES} | Connector_PinHeader_2.54mm:PinHeader_1x06_P2.54mm_Vertical
J4 | 1 | Conn_01x07 |  |  |  |  |  | ${EXCLUDE_FROM_POS_FILES} | Connector_PinHeader_2.54mm:PinHeader_1x07_P2.54mm_Vertical
J6 | 1 | Conn_01x11 |  |  |  |  |  | ${EXCLUDE_FROM_POS_FILES} | Connector_PinHeader_2.54mm:PinHeader_1x11_P2.54mm_Vertical
R1,R2,R3 | 3 | 5.1k | C27834 |  |  |  |  | ${EXCLUDE_FROM_POS_FILES} | Resistor_SMD:R_0805_2012Metric_Pad1.20x1.40mm_HandSolder
R4 | 1 | 10k | C2907219 |  |  |  |  | ${EXCLUDE_FROM_POS_FILES} | Resistor_SMD:R_0805_2012Metric_Pad1.20x1.40mm_HandSolder
R5,R6 | 2 | 0R | C17477 |  |  |  |  | ${EXCLUDE_FROM_POS_FILES} | Resistor_SMD:R_0805_2012Metric_Pad1.20x1.40mm_HandSolder
R7,R8 | 2 | 4.7k | C2907264 | DNP |  |  |  | ${EXCLUDE_FROM_POS_FILES} | Resistor_SMD:R_0805_2012Metric_Pad1.20x1.40mm_HandSolder
SW1 | 1 | SW_SPDT |  |  |  |  |  | ${EXCLUDE_FROM_POS_FILES} | pocket-pet:SW_Slide_SS12D00G3_P2.5mm
SW2,SW3 | 2 | SW_Push |  |  |  |  |  | ${EXCLUDE_FROM_POS_FILES} | Button_Switch_THT:SW_PUSH_6mm
TP1 | 1 | TestPoint |  |  |  |  |  | ${EXCLUDE_FROM_POS_FILES} | TestPoint:TestPoint_Pad_D1.5mm
TP2 | 1 | TestPoint |  |  |  |  |  | ${EXCLUDE_FROM_POS_FILES} | TestPoint:TestPoint_THTPad_D2.0mm_Drill1.0mm
U1 | 1 | MCP73831-2-OT | C424093 |  |  |  |  | ${EXCLUDE_FROM_POS_FILES} | Package_TO_SOT_SMD:SOT-23-5 | http://ww1.microchip.com/downloads/en/DeviceDoc/20001984g.pdf
U2 | 1 | MCP1700x-330xxTT | C39051 |  |  |  |  | ${EXCLUDE_FROM_POS_FILES} | Package_TO_SOT_SMD:SOT-23 | http://ww1.microchip.com/downloads/en/DeviceDoc/20001826D.pdf
U3 | 1 | STM32L433CCTx | C110061 |  |  |  |  | ${EXCLUDE_FROM_POS_FILES} | Package_QFP:LQFP-48_7x7mm_P0.5mm | https://www.st.com/resource/en/datasheet/stm32l433cc.pdf

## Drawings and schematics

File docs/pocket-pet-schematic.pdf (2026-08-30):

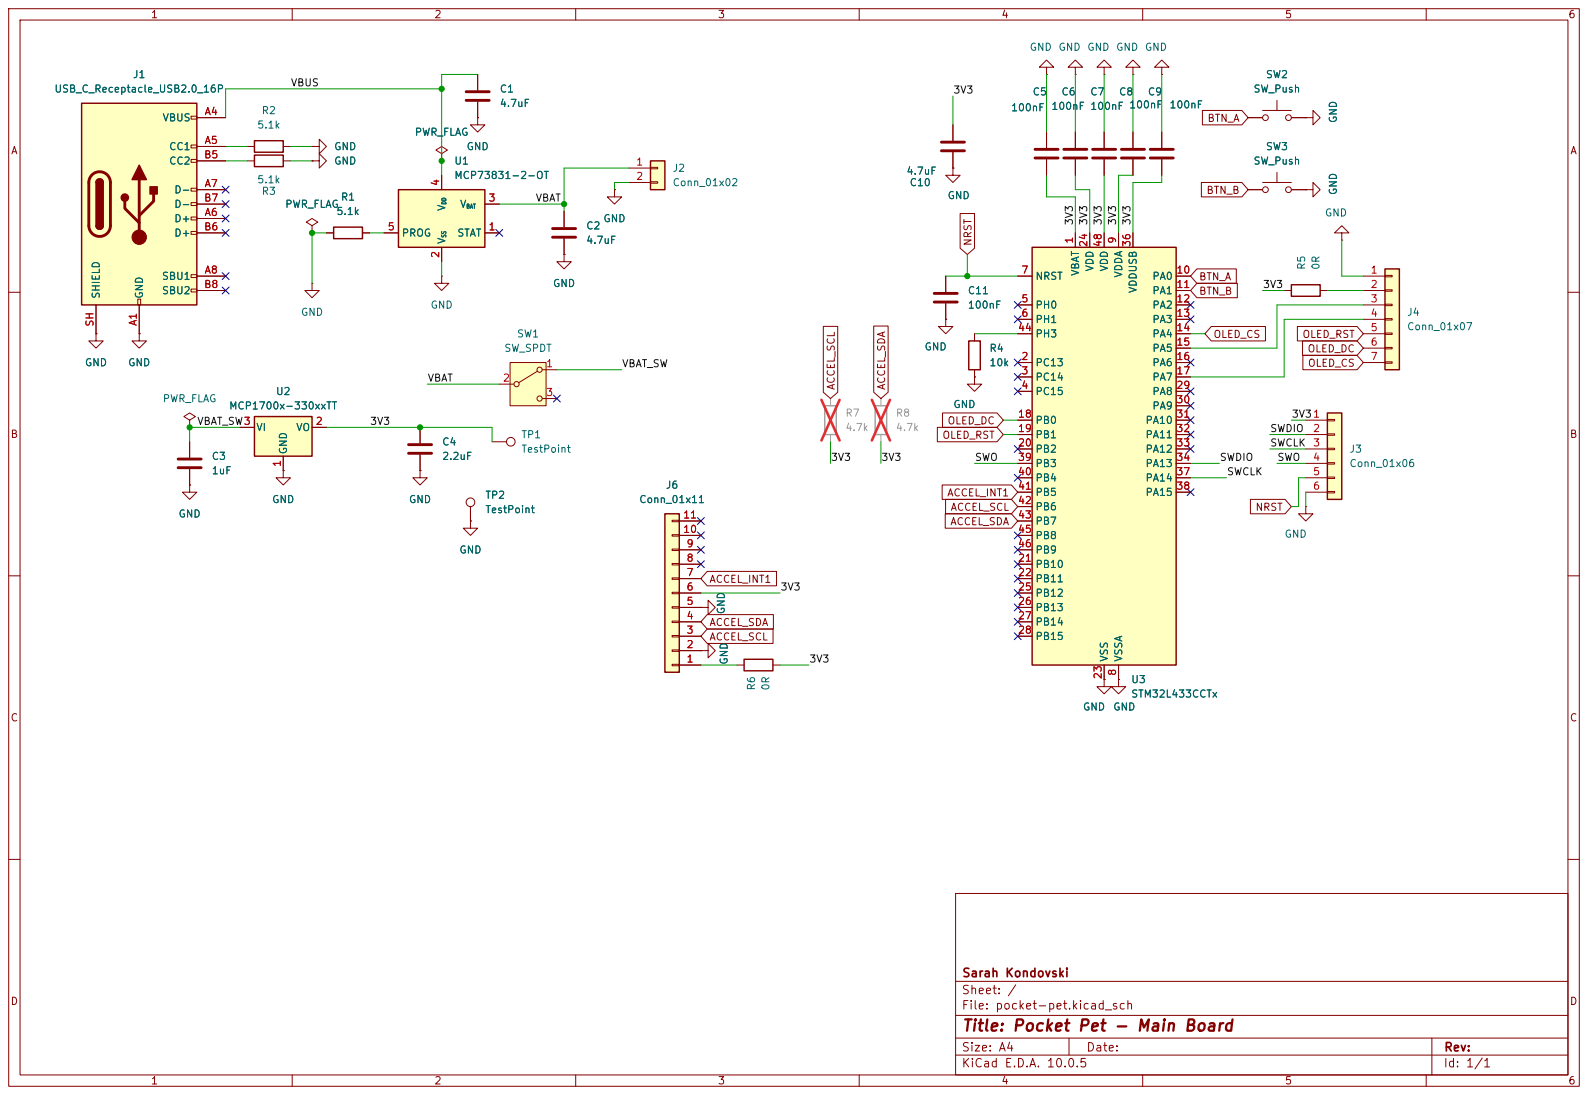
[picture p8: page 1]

VDD 4 PROG 5 U1MCP73831-2-OT GND GND

Sarah Kondovski
Sheet: /
File: pocket-pet.kicad_sch
Title: Pocket Pet - Main Board

Size: A4 | Rev:
KiCad E.D.A. 10.0.5 | Id: 1/1

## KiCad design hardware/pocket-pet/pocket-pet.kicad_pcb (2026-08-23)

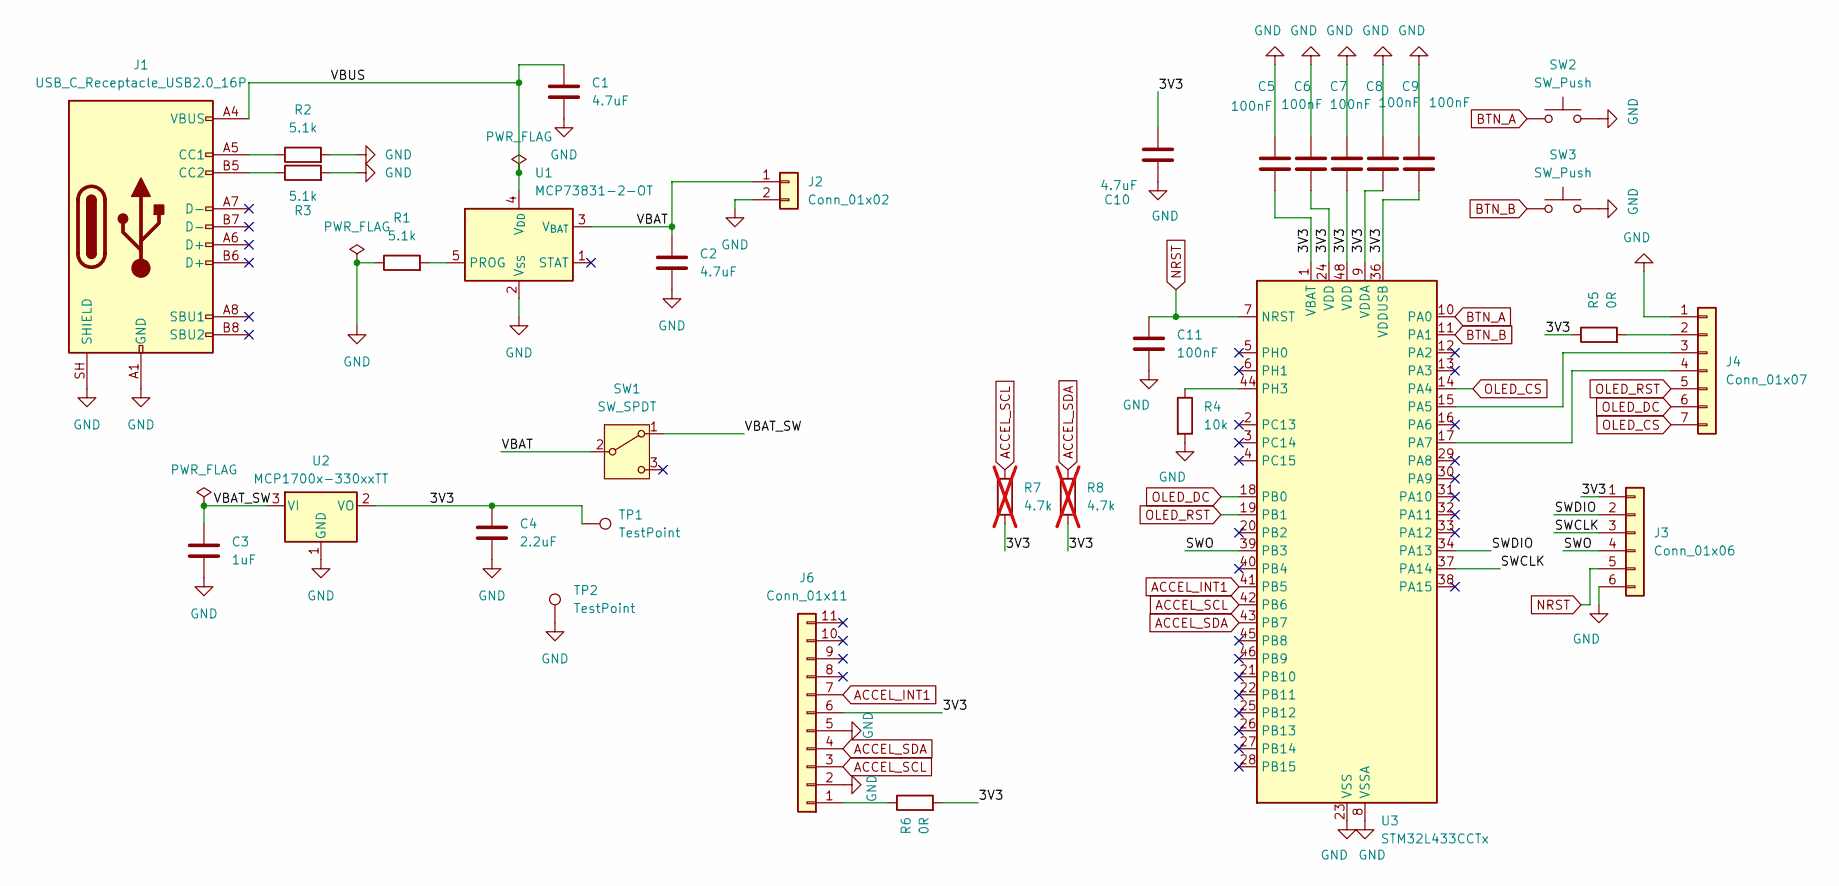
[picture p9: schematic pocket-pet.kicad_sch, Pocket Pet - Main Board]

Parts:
C1, C2, C10: 4.7uF; C_0805_2012Metric_Pad1.18x1.45mm_HandSolder
C3: 1uF; C_0805_2012Metric_Pad1.18x1.45mm_HandSolder
C4: 2.2uF; C_0805_2012Metric_Pad1.18x1.45mm_HandSolder
C5, C6, C7, C8, C9, C11: 100nF; C_0805_2012Metric_Pad1.18x1.45mm_HandSolder
J1: USB_C_Receptacle_USB2.0_16P; USB_C_Receptacle_HRO_TYPE-C-31-M-12
J2: Conn_01x02; JST_PH_S2B-PH-K_1x02_P2.00mm_Horizontal
J3: Conn_01x06; PinHeader_1x06_P2.54mm_Vertical
J4: Conn_01x07; PinHeader_1x07_P2.54mm_Vertical
J6: Conn_01x11; PinHeader_1x11_P2.54mm_Vertical
R1, R2, R3: 5.1k; R_0805_2012Metric_Pad1.20x1.40mm_HandSolder
R4: 10k; R_0805_2012Metric_Pad1.20x1.40mm_HandSolder
R5, R6: 0R; R_0805_2012Metric_Pad1.20x1.40mm_HandSolder
R7, R8: 4.7k; R_0805_2012Metric_Pad1.20x1.40mm_HandSolder; not fitted
SW1: SW_SPDT; SW_Slide_SS12D00G3_P2.5mm
SW2, SW3: SW_Push; SW_PUSH_6mm
TP1: TestPoint; TestPoint_Pad_D1.5mm
TP2: TestPoint; TestPoint_THTPad_D2.0mm_Drill1.0mm
U1: MCP73831-2-OT; SOT-23-5
U2: MCP1700x-330xxTT; SOT-23
U3: STM32L433CCTx; LQFP-48_7x7mm_P0.5mm

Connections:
/3V3: C4.1, C5.1, C6.1, C7.1, C8.1, C9.1, C10.1, J3.1, J6.6, R5.1, R6.2, R7.2, R8.2, TP1.1 (1_1), U2.2 (VO), U3.1 (VBAT), U3.9 (VDDA), U3.24 (VDD), U3.36 (VDDUSB), U3.48 (VDD)
/SWCLK: J3.3, U3.37 (PA14)
/SWDIO: J3.2, U3.34 (PA13)
/SWO: J3.4, U3.39 (PB3)
/VBAT: C2.1, J2.1, SW1.2 (B), U1.3 (V_{BAT})
/VBAT_SW: C3.1, SW1.1 (A), U2.3 (VI)
/VBUS: C1.1, J1.A4 (VBUS), J1.A9 (VBUS), J1.B4 (VBUS), J1.B9 (VBUS), U1.4 (V_{DD})
ACCEL_INT1: J6.7, U3.41 (PB5)
ACCEL_SCL: J6.3, R7.1, U3.42 (PB6)
ACCEL_SDA: J6.4, R8.1, U3.43 (PB7)
BTN_A: SW2.1, U3.10 (PA0)
BTN_B: SW3.1, U3.11 (PA1)
GND: C1.2, C2.2, C3.2, C4.2, C5.2, C6.2, C7.2, C8.2, C9.2, C10.2, C11.2, J1.A1 (GND), J1.A12 (GND), J1.B1 (GND), J1.B12 (GND), J1.SH (SHIELD), J2.2, J3.6, J4.1, J6.2, J6.5, R1.1, R2.2, R3.2, R4.2, SW2.2, SW3.2, TP2.1 (1_1), U1.2 (V_{SS}), U2.1 (GND), U3.8 (VSSA), U3.23 (VSS), U3.35 (VSS), U3.47 (VSS)
NRST: C11.1, J3.5, U3.7 (NRST)
unnamed: J1.A5 (CC1), R2.1
unnamed: J1.B5 (CC2), R3.1
unnamed: J4.2, R5.2
unnamed: J4.3, U3.15 (PA5)
unnamed: J4.4, U3.17 (PA7)
unnamed: J6.1, R6.1
unnamed: R1.2, U1.5 (PROG)
unnamed: R4.1, U3.44 (PH3)
OLED_CS: J4.7, U3.14 (PA4)
OLED_DC: J4.6, U3.18 (PB0)
OLED_RST: J4.5, U3.19 (PB1)

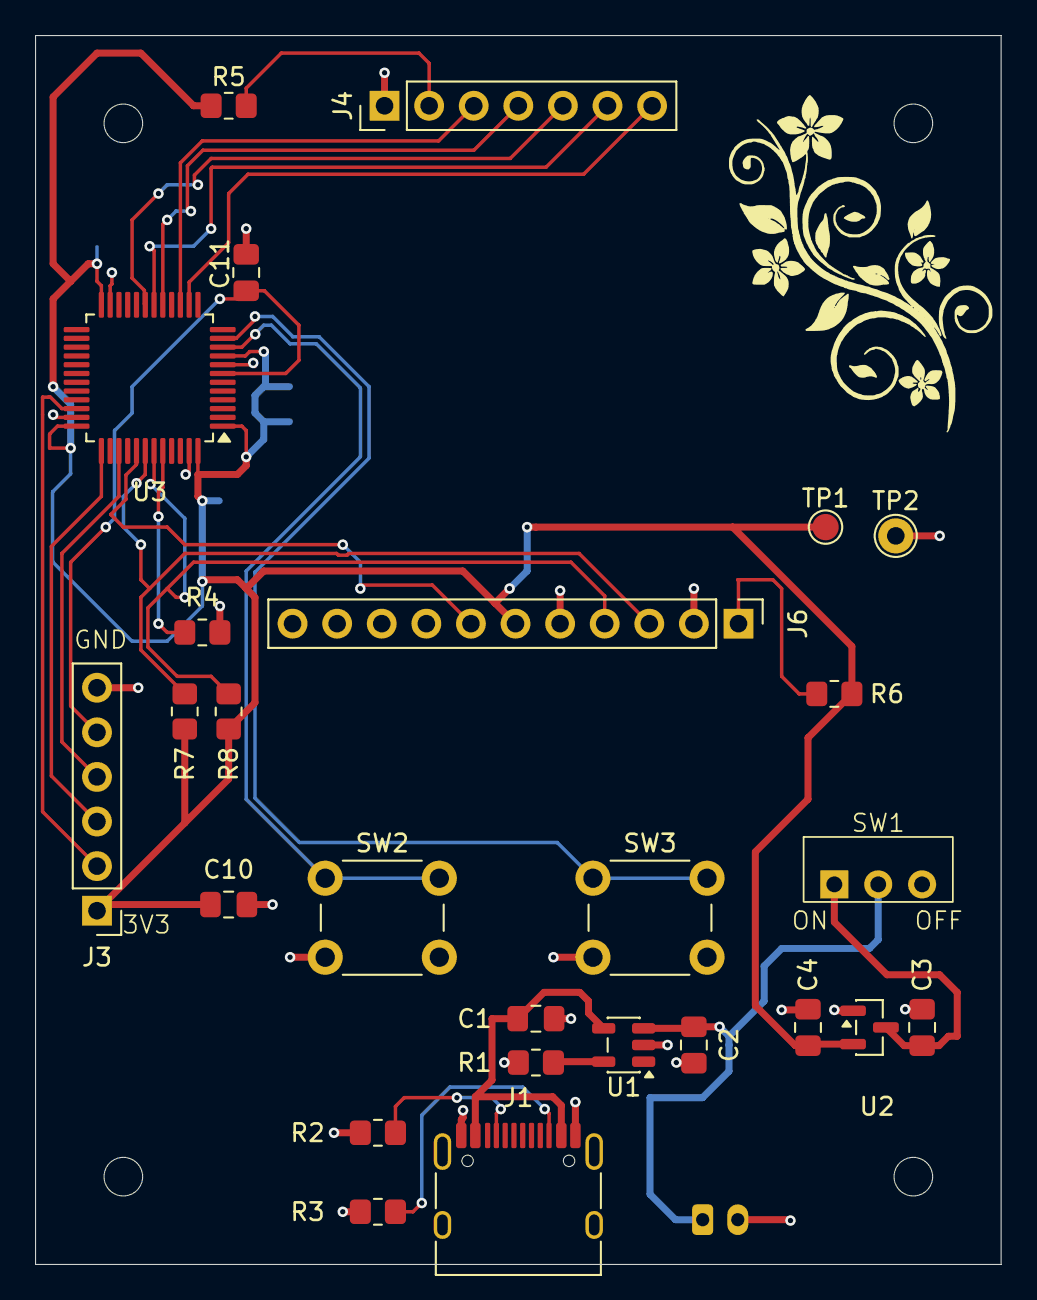
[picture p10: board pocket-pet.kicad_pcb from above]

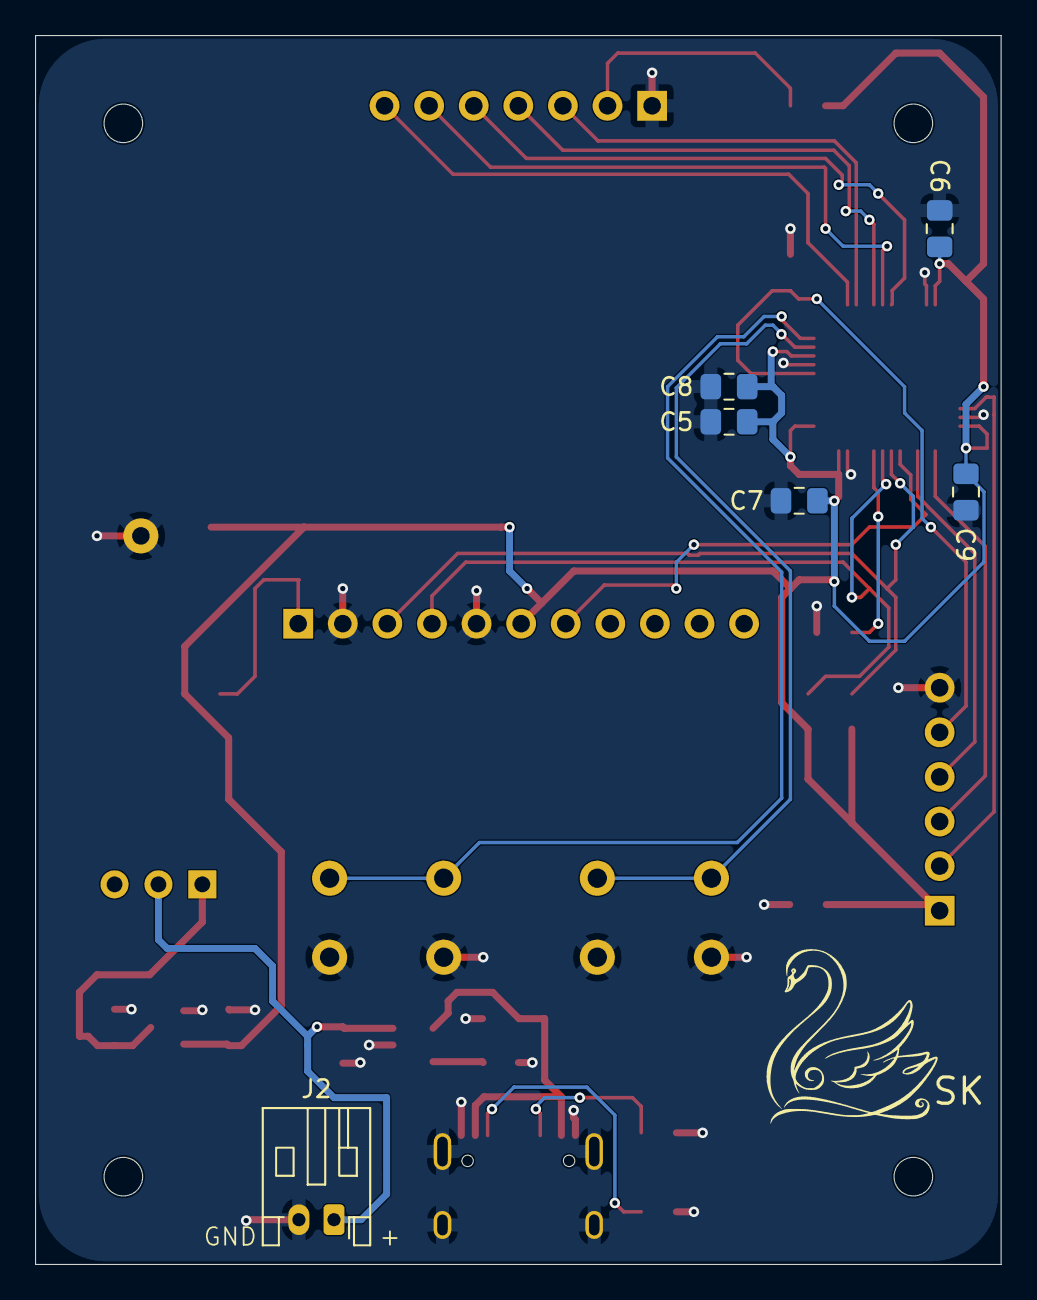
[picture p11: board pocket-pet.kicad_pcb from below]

Board: 2 copper layers, 55.0 x 70.0 mm, 32 parts (6 on the bottom side), 25 nets.

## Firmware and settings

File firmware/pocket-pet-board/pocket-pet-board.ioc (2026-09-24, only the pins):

Mcu.UserName=STM32L433CCTx
PA0.GPIO_Label=BTN_A
PA0.Signal=GPIO_Input
PA1.GPIO_Label=BTN_B
PA1.Signal=GPIO_Input
PA4.GPIO_Label=OLED_CS
PA4.Signal=GPIO_Output
PA5.Signal=SPI1_SCK
PA7.Signal=SPI1_MOSI
PB0.GPIO_Label=OLED_DC
PB0.Signal=GPIO_Output
PB1.GPIO_Label=OLED_RST
PB1.Signal=GPIO_Output
PB5.GPIO_Label=ACCEL_INT1
PB5.Signal=GPIO_Input
PB6.GPIO_Label=ACCEL_SCL
PB6.Signal=I2C1_SCL
PB7.GPIO_Label=ACCEL_SDA
PB7.Signal=I2C1_SDA

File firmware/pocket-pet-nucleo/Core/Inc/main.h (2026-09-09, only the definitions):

#define BTN_A_Pin GPIO_PIN_0
#define BTN_A_GPIO_Port GPIOA
#define BTN_B_Pin GPIO_PIN_1
#define BTN_B_GPIO_Port GPIOA
#define VCP_TX_Pin GPIO_PIN_2
#define VCP_TX_GPIO_Port GPIOA
#define OLED_CS_Pin GPIO_PIN_4
#define OLED_CS_GPIO_Port GPIOA
#define OLED_DC_Pin GPIO_PIN_0
#define OLED_DC_GPIO_Port GPIOB
#define OLED_RST_Pin GPIO_PIN_1
#define OLED_RST_GPIO_Port GPIOB
#define SWDIO_Pin GPIO_PIN_13
#define SWDIO_GPIO_Port GPIOA
#define SWCLK_Pin GPIO_PIN_14
#define SWCLK_GPIO_Port GPIOA
#define VCP_RX_Pin GPIO_PIN_15
#define VCP_RX_GPIO_Port GPIOA
#define LD3_Pin GPIO_PIN_3
#define LD3_GPIO_Port GPIOB

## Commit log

2026-08-22 Project skeleton: KiCad projects, project-local libs, gitignore
    [panel-back.kicad_pcb, panel-back.kicad_sch, panel-front.kicad_pcb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]
2026-08-22 CubeMX pin map: SPI1 display, I2C1 accel, buttons, SWD+SWO
2026-08-22 Power tree: USB-C, MCP73831 charger, battery, switch, custom SS12D00G3 footprint
    [pocket-pet.kicad_sch]
2026-08-22 MCU: power pins, decoupling, BOOT0 pulldown, NRST cap
    [pocket-pet.kicad_sch]
2026-08-22 Schematic complete: display, accelerometer, buttons, ERC clean
    [pocket-pet.kicad_sch]
2026-08-23 Layout complete, DRC clean, boards ordered
    [pocket-pet.kicad_pcb, pocket-pet.kicad_sch]
2026-08-30 Add fabrication docs and Nucleo firmware project for v1.0
    [bom.csv]
2026-09-03 hardware: persist BOM export path and column config
2026-09-03 firmware: hand-written SSD1306 SPI driver
    Transport, init sequence, 1024-byte framebuffer, Bresenham line drawing, and a 5x7 column-major font. Written from the datasheet rather than a vendor library. Not yet verified against hardware.
2026-09-08 docs: add display driver section, update status
2026-09-11 firmware: I2C1 enabled, LIS3DH found at 0x19
2026-09-11 firmware: hand-written LIS3DH I2C driver, validated on hardware
2026-09-11 docs: add motion driver and RTOS architecture sections
2026-09-13 docs: power section verified on hardware
2026-09-14 firmware: LIS3DH address 0x18 on custom board; docs: assembly status
2026-09-14 firmware: share drivers between board and nucleo projects
    ssd1306, lis3dh and pet logic move to firmware/common and are linked into both CubeIDE projects. pocket_pet_pins.h stays per-project since it is the file that differs between targets.
2026-09-15 firmware: port RTOS tasks to custom board project
    Both projects now build against the shared drivers in firmware/common. Board differences (LIS3DH address, absent user LED) are handled by pocket_pet_pins.h and BOARD_ ifdefs.
2026-09-19 firmware: verified on custom board; fix task stack overflow
    [lis3dh.c]
2026-09-22 fix: display task stack overflow; set stack sizes in .ioc so regeneration keeps them
    The default task ran on CubeMX's 512-byte default and crashed under input bursts. An earlier hand fix was reverted by regeneration. Stacks now 2 KB each, heap 16 KB, stack overflow checking enabled.
    [pocket-pet-board.ioc]
2026-09-24 fix: I2C timing register was still set for 400 kHz despite Standard Mode in the .ioc
    CubeMX did not recalculate hi2c1.Init.Timing when the speed mode changed, so the bus ran at 400 kHz with 10k pull-ups and no ground plane. Intermittent LIS3DH init failures traced to this. Timing set by hand to the 100 kHz value.
    [pocket-pet-board.ioc]

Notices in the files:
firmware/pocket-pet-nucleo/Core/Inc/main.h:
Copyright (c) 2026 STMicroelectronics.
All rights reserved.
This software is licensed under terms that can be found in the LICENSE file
